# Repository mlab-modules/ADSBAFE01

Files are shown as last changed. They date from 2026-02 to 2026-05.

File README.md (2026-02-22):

# ADSBAFE01 - 1090 MHz ADS-B analog front-end

ADSBAFE01 is a complete 1090 MHz analog front-end for ADS-B / Mode-S reception. The module integrates RF filtering, low-noise amplification, logarithmic power detection and high-speed pulse shaping. It is intended to deliver a logic pulse stream corresponding to the RF envelope together with auxiliary RSSI information for sensitivity control and signal quality evaluation.

## Intended use

ADSBAFE01 is designed as an analog front-end for custom ADS-B receivers where digital demodulation and message decoding are implemented externally (MCU, FPGA, SDR backend, etc.). The module does not perform protocol decoding; it delivers time-accurate envelope pulses and auxiliary RSSI information for higher-layer processing.

## Functional overview

The RF signal enters through a 50 Ω MCX connector and immediately passes a 1090 MHz SAW band-pass filter (~30 MHz bandwidth). This suppresses strong out-of-band signals before amplification. The filtered signal is amplified by a BGA2818 LNA with approximately +30 dB gain. Then logarithmic power detector (AD8313) converts the RF envelope into a baseband voltage proportional to signal level. This node is intentionally kept lightly loaded because additional capacitance directly degrades slew rate and therefore timing accuracy of the detected pulses (see schematic notes ).

The detector output is processed in two parallel paths:

1. A high-speed comparator path generating digital pulses.
2. A peak-detection and sample-and-hold path providing RSSI information.

This separation allows reliable time-domain decoding while still exposing signal strength information for adaptive thresholding or diagnostics.

### Pulse extraction path

The comparator (MCP6566) converts the detector voltage into a CMOS pulse stream. Its propagation delay is on the order of 50 ns with ~20 ns fall time, which is sufficient for 1 µs ADS-B pulses.

The detection threshold is not fixed. It is derived from bias networks controlled by a 100 kΩ digital potentiometer (MCP4017, I²C). This allows software-controlled sensitivity adjustment without hardware modification. Low-frequency RC filtering in the bias network (fc ≈ 159 Hz) stabilizes the reference and suppresses slow variations.

The resulting `PULSES` output can be directly connected to:

* MCU timer capture input
* FPGA input
* Fast interrupt-capable GPIO

### RSSI and peak detection

For signal strength evaluation, the module implements an active peak detector (op-amp based). During a decode window, the peak value of the (inverted) log-detector output is sampled and held. The reset discharge time constant is approximately 44 ns, with ~95 % discharge in ~132 ns, enabling packet-level RSSI measurements without excessive memory between adjacent pulses.

The analog RSSI signal can be read by an external ADC if quantitative signal strength estimation is required.

### Electrical parameters

| Parameter | Value / Description |
| --- | --- |
| Supply voltage | 3.3 V |
| RF frequency | 1090 MHz (ADS-B / Mode-S) |
| RF input impedance | 50 Ω |
| LNA gain | ~+30 dB |
| Comparator delay | ~50 ns |
| Logic levels | 3.3 V CMOS |
| Threshold control  | I²C digital potentiometer |

The module includes input decoupling (10 µF + 100 nF) and supply protection (TVS diode) as shown in the schematic .

### Connectors

#### RF input (J3)

Type: MCX with impedance: 50 Ω

#### IO header (J1, 2×12)

The IO header exposes digital control, RSSI and interface signals. Series resistors provide basic IO protection and edge damping.

| Signal | Direction | Description |
| --- | --- | --- |
| PULSES | Output | Digital ADS-B envelope pulses |
| RF_LEVEL | Output (analog) | Log-detector RSSI voltage |
| DECODE | Input | Enables RSSI peak sampling |
| RSSI_HOLD | Input | Controls sample/hold state |
| RSSI_DSCHRG | Input | Forces RSSI capacitor discharge |
| MTL_HI_PWM  | Input | Comparator reference control (high) |
| MTL_LO_PWM  | Input | Comparator reference control (low)  |
| MTL_HI_BIAS | Internal / test | Bias node (high threshold) |
| MTL_LO_BIAS | Internal / test | Bias node (low threshold) |
| I2C1_SCL | Input | I²C clock (digital potentiometer) |
| I2C1_SDA | Bidirectional | I²C data |
| +3V3 | — | Supply |
| GND | — | Ground |

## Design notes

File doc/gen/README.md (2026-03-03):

# PCB

Board size: 50.29x50.29 mm (1.98x1.98 inches)

- This is the size of the rectangle that contains the board
- Thickness: 1.58 mm (62 mils)
- Material: FR4 (JLC 7628)
- Finish: ENIG
- Layers: 2
- Copper thickness: 35 µm

Solder mask: TOP / BOTTOM

- Color: Black

Silk screen: TOP / BOTTOM

- Color: White

Stackup:

Impedance controlled: YES

| Name | Type | Color | Thickness [µm]| Material | Er | Loss tan |
|---|---|---|---|---|---|---|
| F.SilkS | Top Silk Screen | White | | Liquid Photo | | |
| F.Paste | Top Solder Paste | | | | | |
| F.Mask | Top Solder Mask | Black | 15 | Epoxy (JLC) | 3.8 | 0.020 |
| F.Cu | copper | | 35 | | | |
| dielectric 1 | core | FR4 natural | 1484 | FR4 (JLC 7628)  | 4.4 | 0.020 |
| B.Cu | copper | | 35 | | | |
| B.Mask | Bottom Solder Mask | Black | 15 | Epoxy (JLC) | 3.8 | 0.020 |
| B.Paste | Bottom Solder Paste  | | | | | |
| B.SilkS | Bottom Silk Screen | White | | Liquid Photo | | |

# Important sizes

Clearance: 0.2 mm (8 mils)

Track width: 0.2 mm (8 mils)

- By design rules: 0.2 mm (8 mils)

Drill: 0.4 mm (16 mils)

- Vias: 0.4 mm (16 mils) [Design: 0.4 mm (16 mils)]
- Pads: 1.0 mm (39 mils)
- The above values are real drill sizes, they add 0.1 mm (4 mils) to plated holes (PTH)

Via: 0.7/0.3 mm (28/12 mils)

- By design rules: 0.3/0.3 mm (12/12 mils)
- Micro via: yes [0.2/0.1 mm (8/4 mils)]
- Buried/blind via: yes
- Total: 212 (thru: 212 buried/blind: 0 micro: 0)

Outer Annular Ring: 0.15 mm (6 mils)

- By design rules: 0.0 mm (0 mils)

Eurocircuits class: 4C
- Using min drill 0.4 mm for an OAR of 0.15 mm

# General stats

Components count: (SMD/THT)

- Top: 0/7 (THT)
- Bottom: 50/0 (SMD)

Defined tracks:

- 0.15 mm (6 mils)
- 0.25 mm (10 mils)
- 0.4 mm (16 mils)
- 0.6 mm (24 mils)
- 0.8 mm (31 mils)

Used tracks:

- 0.2 mm (8 mils) (8) defined: no
- 0.25 mm (10 mils) (153) defined: yes
- 0.3 mm (12 mils) (60) defined: no
- 0.5 mm (20 mils) (14) defined: no

Defined vias:

- 0.4/0.3 mm (16/12 mils)
- 0.8/0.4 mm (31/16 mils)

Used vias:

- 0.7/0.3 mm (28/12 mils) (Count: 212, Aspect: 2.3 A) defined: no

Holes (excluding vias):

- 0.89 mm (35 mils) (30)
- 1.5 mm (59 mils) (1)
- 1.7 mm (67 mils) (4)
- 3.0 mm (118 mils) (4)

Oval holes:

Drill tools (including vias and computing adjusts and rounding):

- 0.4 mm (16 mils) (212)
- 1.0 mm (39 mils) (30)
- 1.6 mm (63 mils) (1)
- 1.8 mm (71 mils) (4)
- 3.1 mm (122 mils) (4)

Solder paste stats:

Using a paste with 87.75 % alloy, that has an specific gravity for the alloy of 7.4 g/cm³
and 1.0 g/cm³ for the flux. This paste has an specific gravity of  4.15 g/cm³.

The stencil thickness is  0.12 mm.

| Side | Pads with paste | Area [mm²] | Paste [g] |
|---|---|---|---|
| Total  | 161 | 187.31 | 0.93 |

Note: this is just an approximation to the theoretical value. Margins of the solder mask and waste aren't computed.

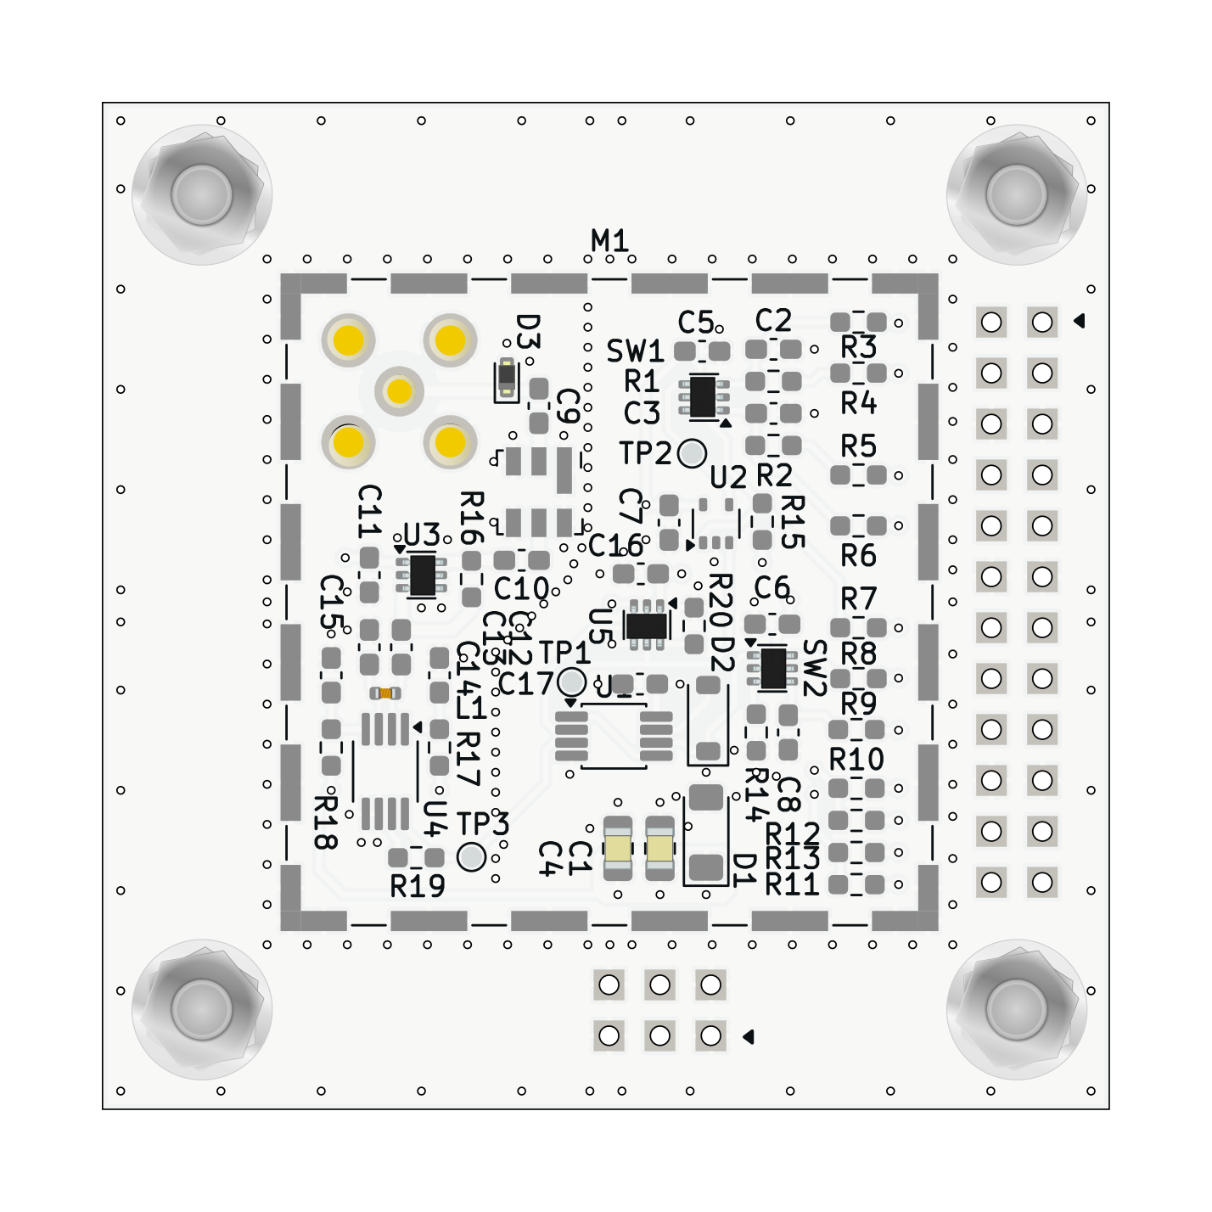
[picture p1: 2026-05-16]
doc/gen/img/ADSBAFE01-bottom.png

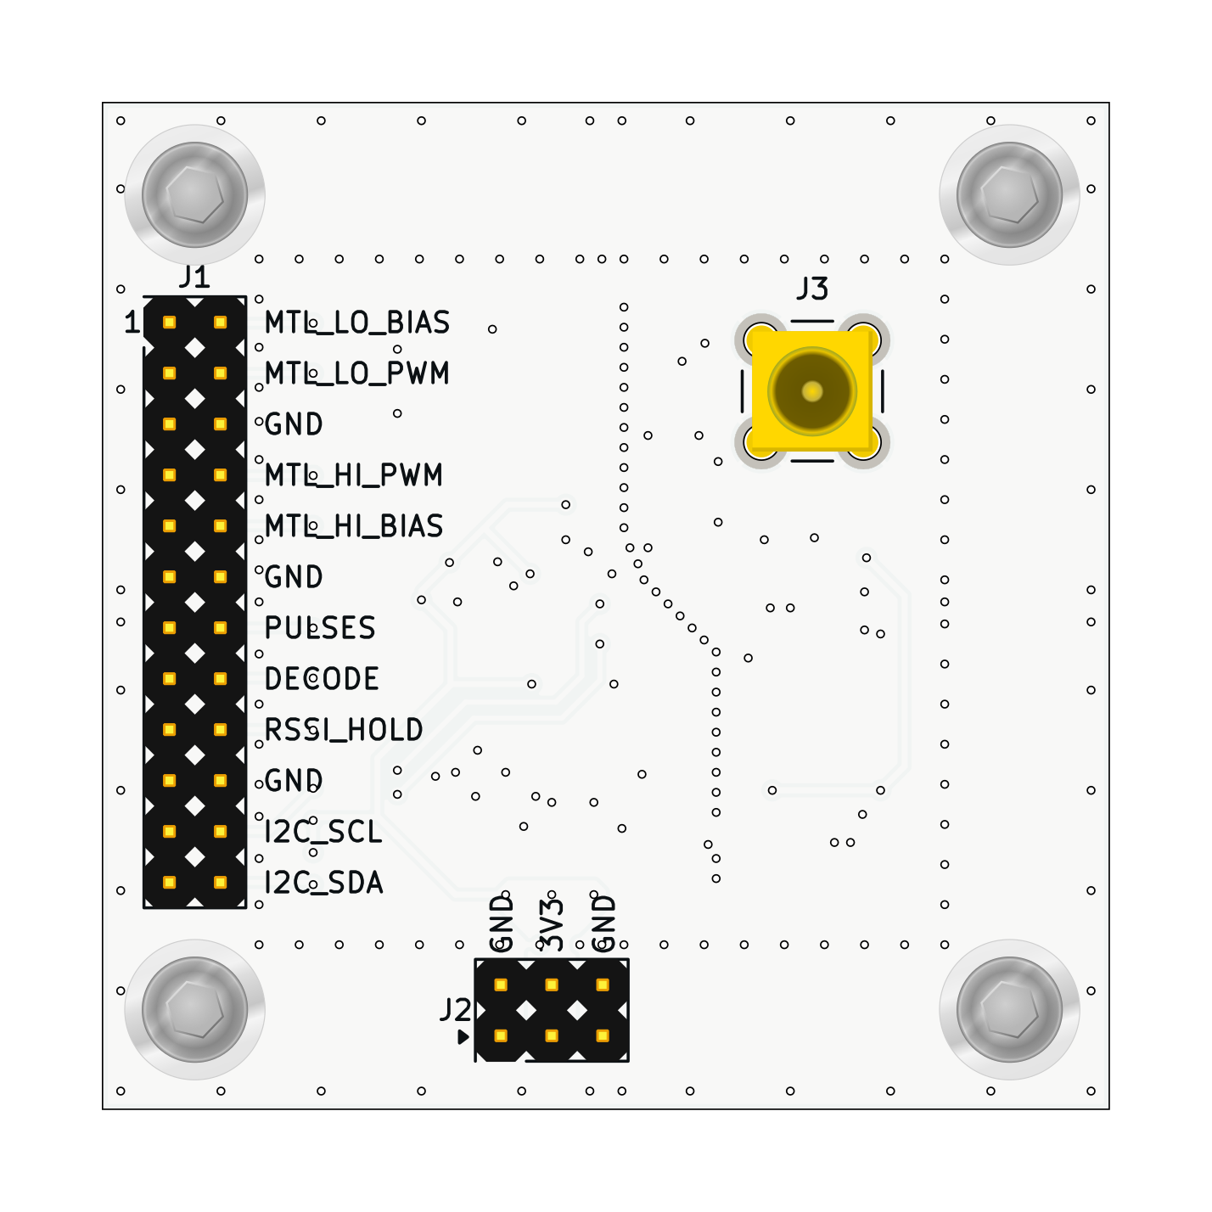
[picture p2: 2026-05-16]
doc/gen/img/ADSBAFE01-top.png

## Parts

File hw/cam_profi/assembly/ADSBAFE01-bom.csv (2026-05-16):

Component | Description | Part | References | Value | Footprint | Quantity Per PCB | Datasheet | mpn | ust_id
1 | Unpolarized capacitor | C | C12C13 | 3pF | C_0603_1608Metric_Pad1.08x0.95mm_HandSolder | 2 |  | CQ0402CRNPO9BN3R0
2 | Unpolarized capacitor | C | C9C10 | 39pF | C_0603_1608Metric_Pad1.08x0.95mm_HandSolder | 2 |  | CC0402JRNPO9BN390
3 | Unpolarized capacitor | C | C8C11 | 22nF | C_0603_1608Metric_Pad1.08x0.95mm_HandSolder | 2 |  | CC0402KRX7R9BB223
4 | Unpolarized capacitor | C | C2C3C5C6C7C14C15C16C17 | 0.1uF | C_0603_1608Metric_Pad1.08x0.95mm_HandSolder | 9 |  | CC0402KRX7R7BB104
5 | Unpolarized capacitor | C | C4 | 100nF | C_0805_2012Metric_Pad1.18x1.45mm_HandSolder | 1 |  |  | 5c70984712875079b91f8b4c
6 | Unpolarized capacitor | C | C1 | 10uF | C_0805_2012Metric_Pad1.18x1.45mm_HandSolder | 1 |  |  | 5c70984812875079b91f8bbe
7 | Schottky diode | D_Schottky | D2 | 20V 1A | D_SOD-123 | 1 |  | PMEG2010ER,115
8 | Bidirectional transient-voltage-suppression diode | D_TVS | D3 | 3.3VWM 0.6pF | D_SOD-523 | 1 | https://www.onsemi.com/pdf/datasheet/esd7351-d.pdf | ESD7351XV2T1G
9 | Zener diode | D_Zener | D1 | BZV55C-6,2V | D_MiniMELF | 1 |  |  | 604b0326128750769e5b0f93
10 | 2x03 2.54 mm pitch header, 2 pins next to each other are connected | HEADER_2x03_PARALLEL | J2 | HEADER_2x03_PARALLEL | Straight_2x03 | 1
11 | 2x12 2.54 mm pitch header, 2 pins next to each other are connected | HEADER_2x12_PARALLEL | J1 | HEADER_2x12_PARALLEL | Straight_2x12 | 1
12 | coaxial connector (BNC, SMA, SMB, SMC, Cinch/RCA, LEMO, ...) | Conn_Coaxial | J3 | MCX 6GHz 50R | MCX | 1 |  | U.FL-R-SMT-1(80)
13 | Inductor | L | L1 | 8.2nH RF | L_0402_1005Metric | 1 |  | 0402HP-8N2XJRW
14 | Two-piece EMI RF shielding cabinet | RFShield_TwoPieces | M1 | RFShield_TwoPieces | Laird_Technologies_BMI-S-204-F_32.00x32.00mm | 1 |  |  | 5c72751c1287500b4e11301a
15 | Resistor | R | R16R19 | 0R | R_0603_1608Metric_Pad0.98x0.95mm_HandSolder | 2 |  | RC0402JR-070RL
16 | Resistor | R | R17R18 | 10R | R_0603_1608Metric_Pad0.98x0.95mm_HandSolder | 2 |  | RC0402FR-0710RL
17 | Resistor | R | R3R4R5R6R7R8R9R10R11R14 | 20R | R_0603_1608Metric_Pad0.98x0.95mm_HandSolder | 10 |  | RC0402FR-0710KL RC0402FR-0720RL
18 | Resistor | R | R12R13R15R20 | 1k | R_0603_1608Metric_Pad0.98x0.95mm_HandSolder | 4 |  | RC0402FR-071KL
19 | Resistor | R | R1R2 | 10k | R_0603_1608Metric_Pad0.98x0.95mm_HandSolder | 2 |  | RC0402FR-0710KL
20 |  | SN74LVC1G3157 | SW1SW2 | SN74LVC1G3157 | SOT-363_SC-70-6 | 2 | https://www.ti.com/lit/ds/symlink/sn74lvc1g3157.pdf | SN74LVC1G3157DCKR
21 | 100 MHz to 2.5 GHz, 80 dB Logarithmic Detector / Controller, MSOP-8 | AD8313xRM | U4 | AD8313xRM | MSOP-8_3x3mm_P0.65mm | 1 | https://www.analog.com/media/en/technical-documentation/data-sheets/AD8313.pdf | AD8313ARMZ
22 | MMIC wideband amplifier, DC-2.2GHz, +30dB @ 2150MHz, 3.3V, SOT-363 | BGA2818 | U3 | BGA2818 | SOT-363_SC-70-6 | 1 | https://www.nxp.com/docs/en/data-sheet/BGA2818.pdf | BGA2818,115
23 | Low-Cost 128-Step Volatile I2C Digital Potentiometer, SC-70-6 | MCP4017-xxxxLT | U5 | MCP4017-104E 100k | SOT-363_SC-70-6 | 1 | http://ww1.microchip.com/downloads/en/DeviceDoc/22147a.pdf | MCP4017T-104E/LT
24 | Single 1.8V Low-Power Open-Drain Output Comparator, SOT-23-5/SC-70 | MCP6566 | U2 | MCP6566 | SOT-353_SC-70-5 | 1 | http://ww1.microchip.com/downloads/en/DeviceDoc/MCP6566-6R-6U-7-9-1.8V-Low-Power-Open-Drain-Output-Comparator-DS20002143G.pdf | MCP6566T-E/LT
25 | 200-MHz, Rail-to-Rail I/O, VSSOP-8 | TLV3542 | U1 | TLV3542 | VSSOP-8_3x3mm_P0.65mm | 1 | https://www.ti.com/lit/ds/symlink/tlv3542.pdf | TLV3542IDGKR
26 |  | SAW-6_Filter | X1 | SF2321D | Filter_SAW-6_3.8x3.8mm | 1 | https://www.mouser.com/datasheet/2/1100/sf2321d-1917641.pdf | SF2321D

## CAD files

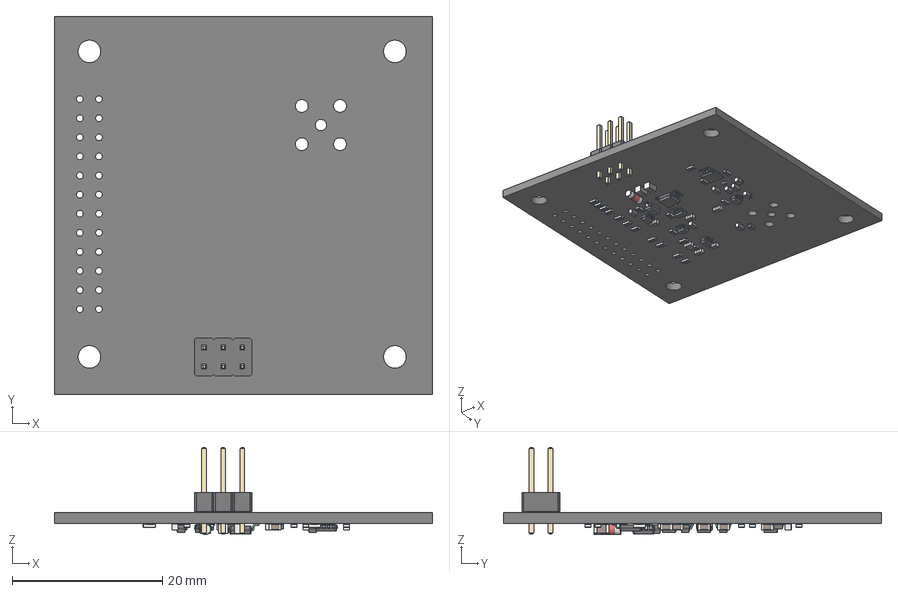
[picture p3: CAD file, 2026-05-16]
doc/gen/ADSBAFE01.step
50.3 x 50.3 x 11.6 mm
PinHeader_2x03_P2.54mm_Vertical
D_SOD-523
R_0603_1608Metric x 20
C_0603_1608Metric x 15
C_0805_2012Metric x 2
MSOP-8_3x3mm_P0.65mm
SOT-363_SC-70-6 x 4
VSSOP-8_3x3mm_P0.65mm
D_MiniMELF
D_SOD-123
L_0402_1005Metric
SOT-353_SC-70-5
kibot_9g2yru_4_PCB

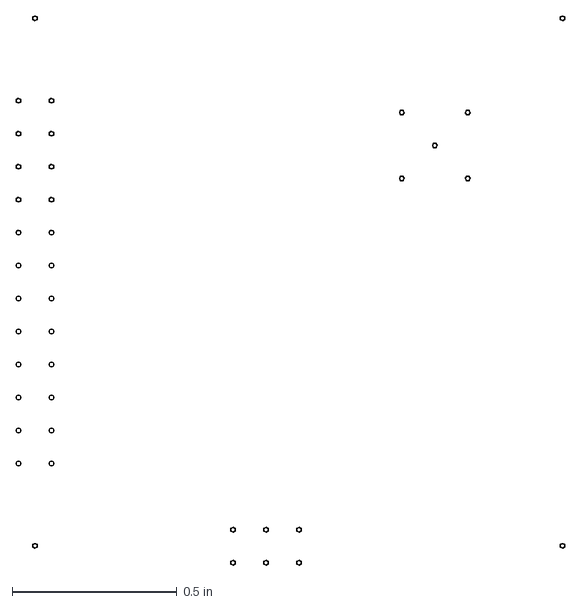
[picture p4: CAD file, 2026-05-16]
doc/gen/dxf/ADSBAFE01-User_2.dxf
1.66 x 1.66 in

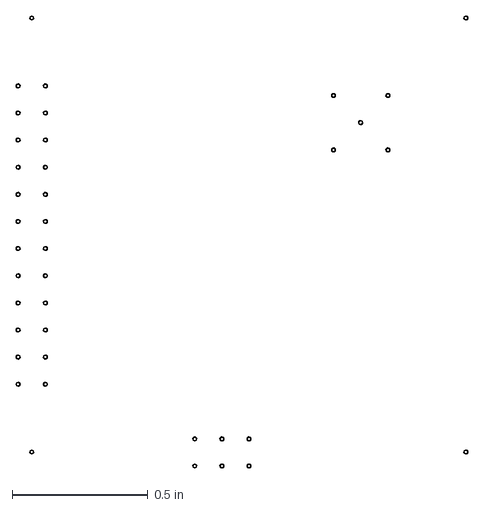
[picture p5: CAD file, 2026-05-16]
doc/gen/dxf/ADSBAFE01-F_Adhesive.dxf
1.66 x 1.66 in

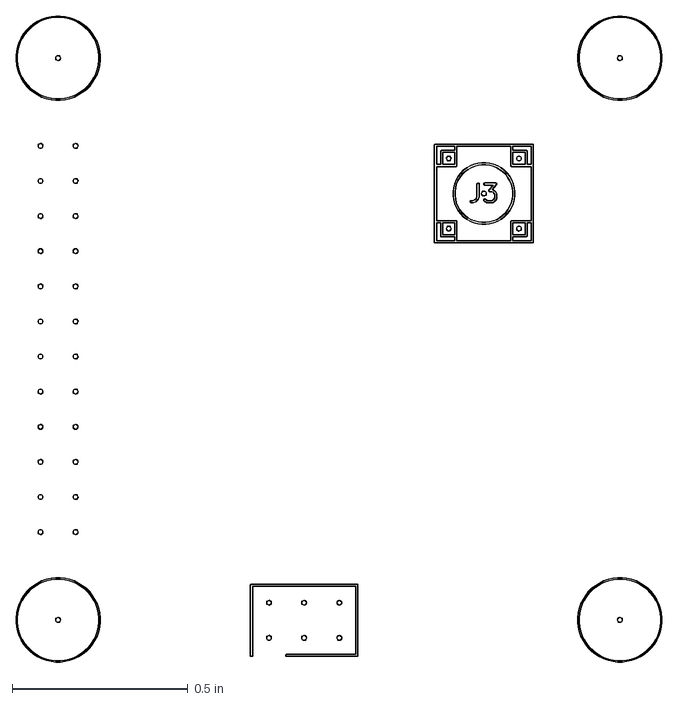
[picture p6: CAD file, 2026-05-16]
doc/gen/dxf/ADSBAFE01-F_Fab.dxf
1.84 x 1.84 in

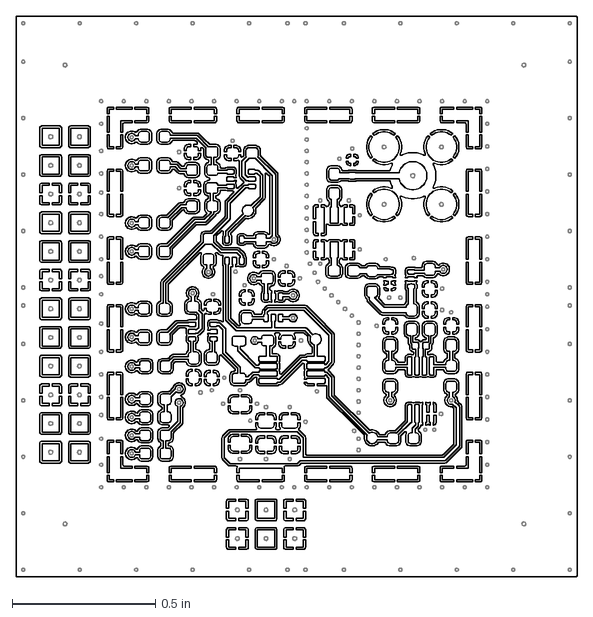
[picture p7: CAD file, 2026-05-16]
doc/gen/dxf/ADSBAFE01-B_Cu.dxf
1.96 x 1.96 in

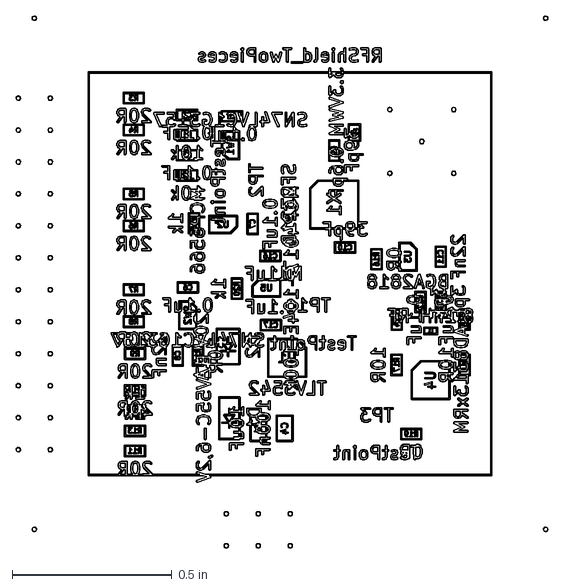
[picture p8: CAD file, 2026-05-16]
doc/gen/dxf/ADSBAFE01-B_Fab.dxf
1.66 x 1.66 in

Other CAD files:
doc/gen/dxf/ADSBAFE01-B_Courtyard.dxf
doc/gen/dxf/ADSBAFE01-B_Mask.dxf
doc/gen/dxf/ADSBAFE01-B_Paste.dxf
doc/gen/dxf/ADSBAFE01-B_Silkscreen.dxf
doc/gen/dxf/ADSBAFE01-Edge_Cuts.dxf
doc/gen/dxf/ADSBAFE01-F_Cu.dxf
doc/gen/dxf/ADSBAFE01-F_Mask.dxf
doc/gen/dxf/ADSBAFE01-F_Silkscreen.dxf

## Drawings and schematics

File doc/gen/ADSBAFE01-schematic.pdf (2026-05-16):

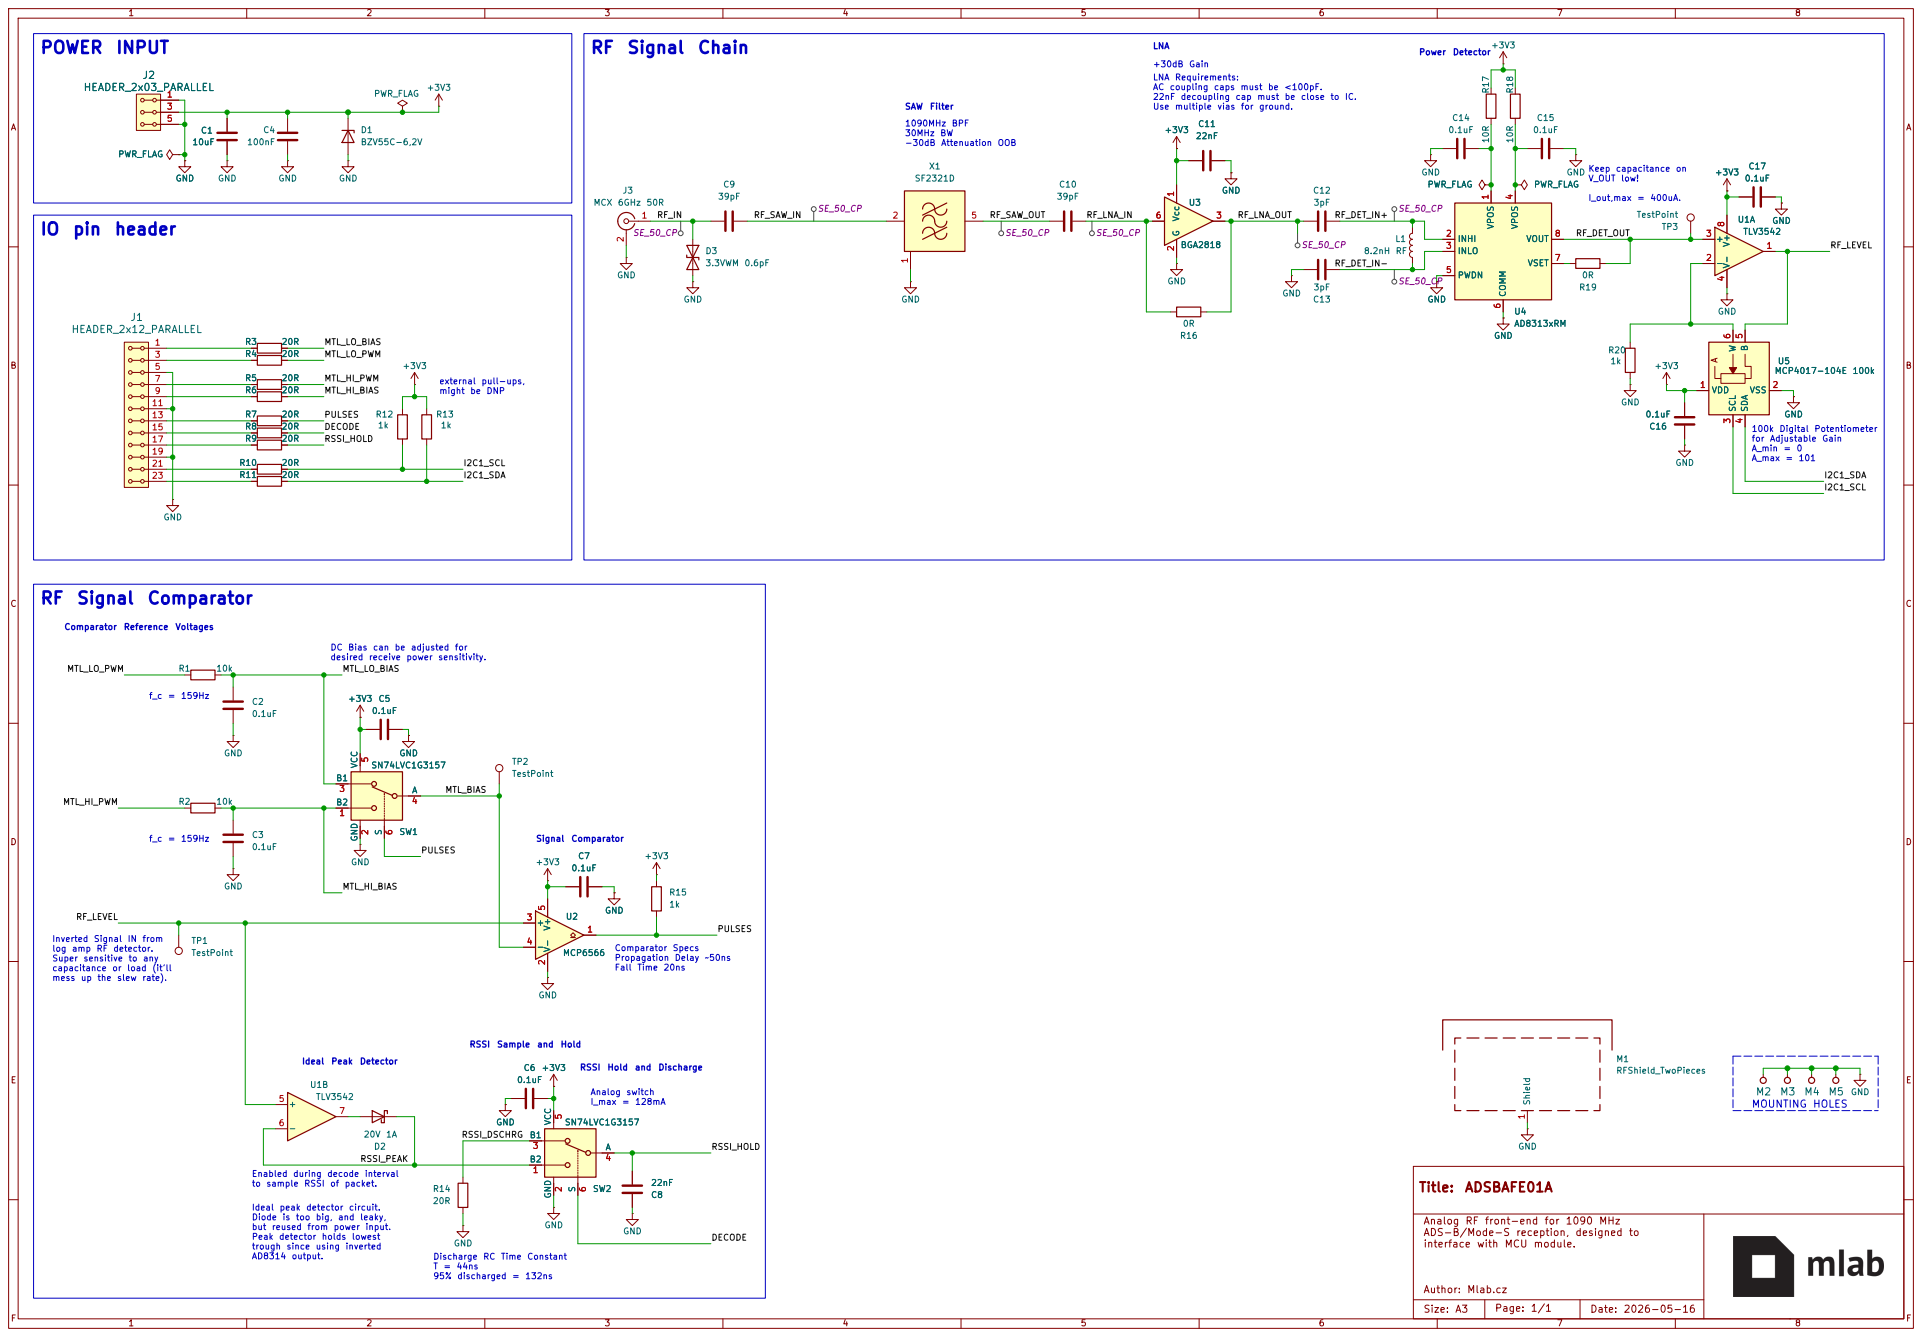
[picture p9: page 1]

A_max = 101 +30dB Gain 1090MHz BPF 30MHz BW -30dB Attenuation OOB

I_out,max = 400uA. LNA Requirements: AC coupling caps must be <100pF. 22nF decoupling cap must be close to IC. Use multiple vias for ground.

VSS

Propagation Delay ~50ns Fall Time 20ns DC Bias can be adjusted for desired receive power sensitivity.
MTL_HI_BIAS MTL_LO_BIAS

Inverted Signal IN from
log amp RF detector. Super sensitive to any capacitance or load (it'll mess up the slew rate).

DECODE RSSI Sample and Hold

RSSI Hold and Discharge

Enabled during decode interval to sample RSSI of packet.

Ideal peak detector circuit. Diode is too big, and leaky, but reused from power input. Peak detector holds lowest

Analog RF front-end for 1090 MHz ADS-B/Mode-S reception, designed to interface with MCU module.

trough since using inverted
AD8314 output.

Size: A3 | Page: 1/1 | Date: 2026-05-16

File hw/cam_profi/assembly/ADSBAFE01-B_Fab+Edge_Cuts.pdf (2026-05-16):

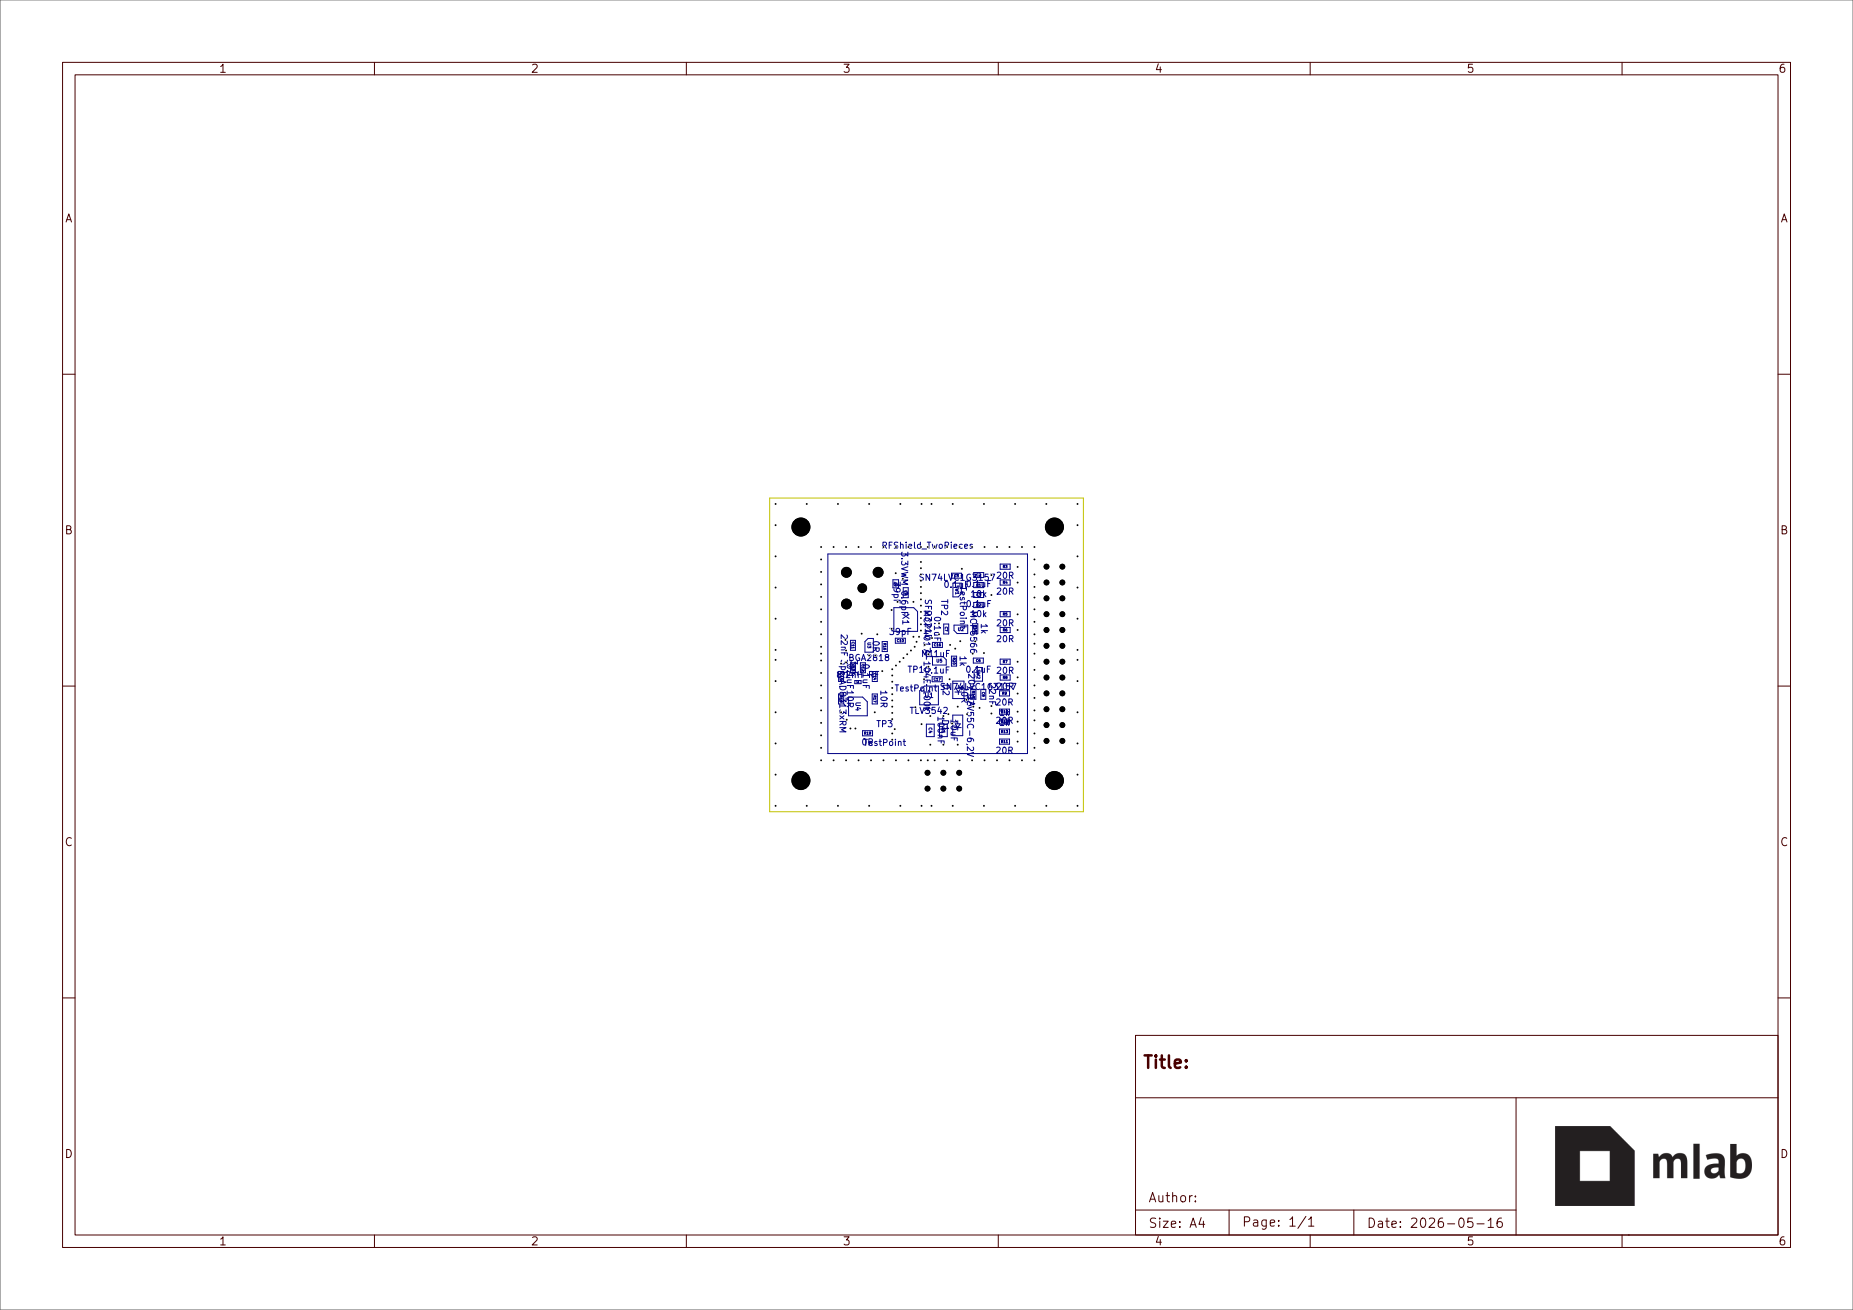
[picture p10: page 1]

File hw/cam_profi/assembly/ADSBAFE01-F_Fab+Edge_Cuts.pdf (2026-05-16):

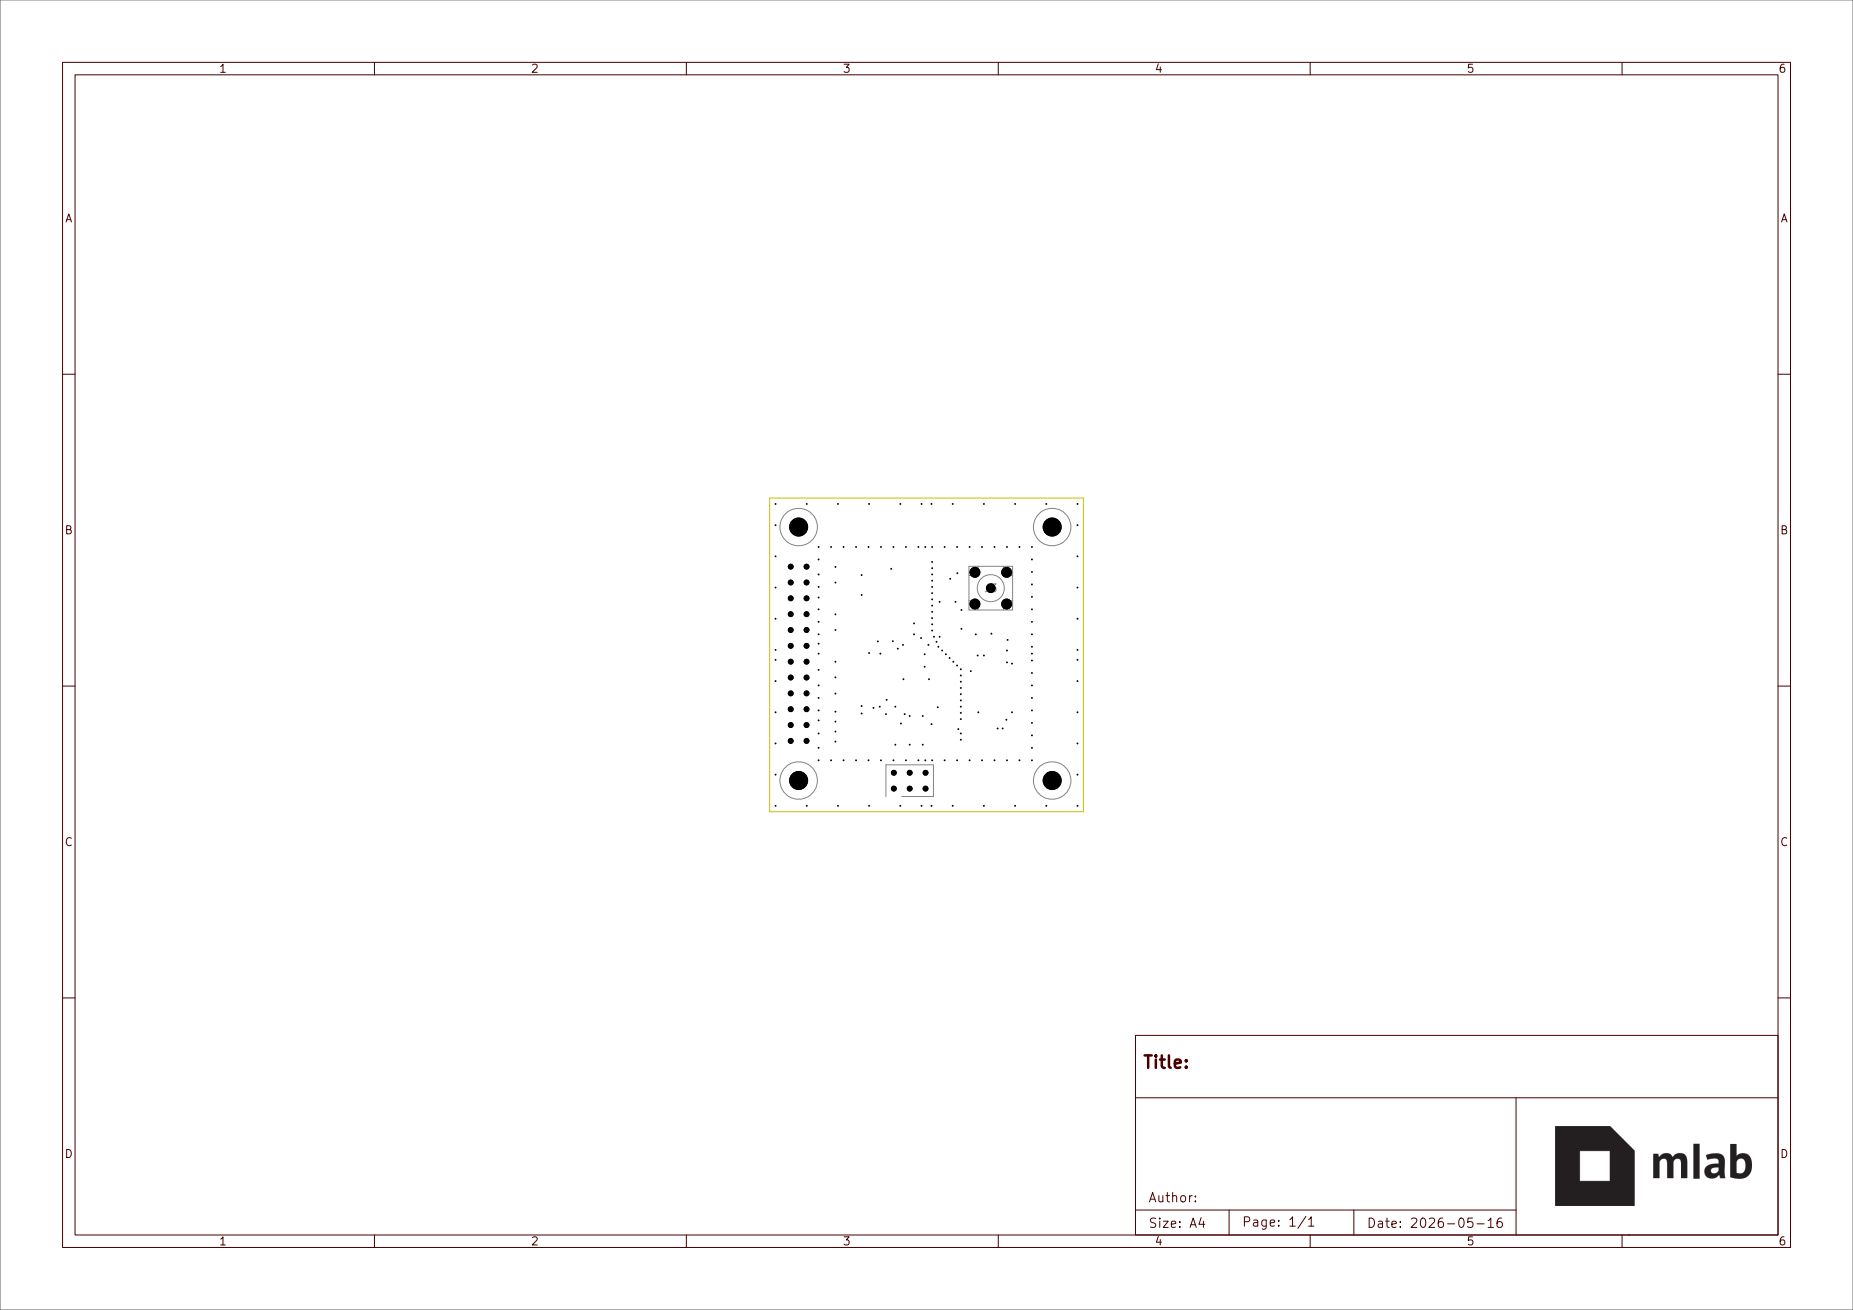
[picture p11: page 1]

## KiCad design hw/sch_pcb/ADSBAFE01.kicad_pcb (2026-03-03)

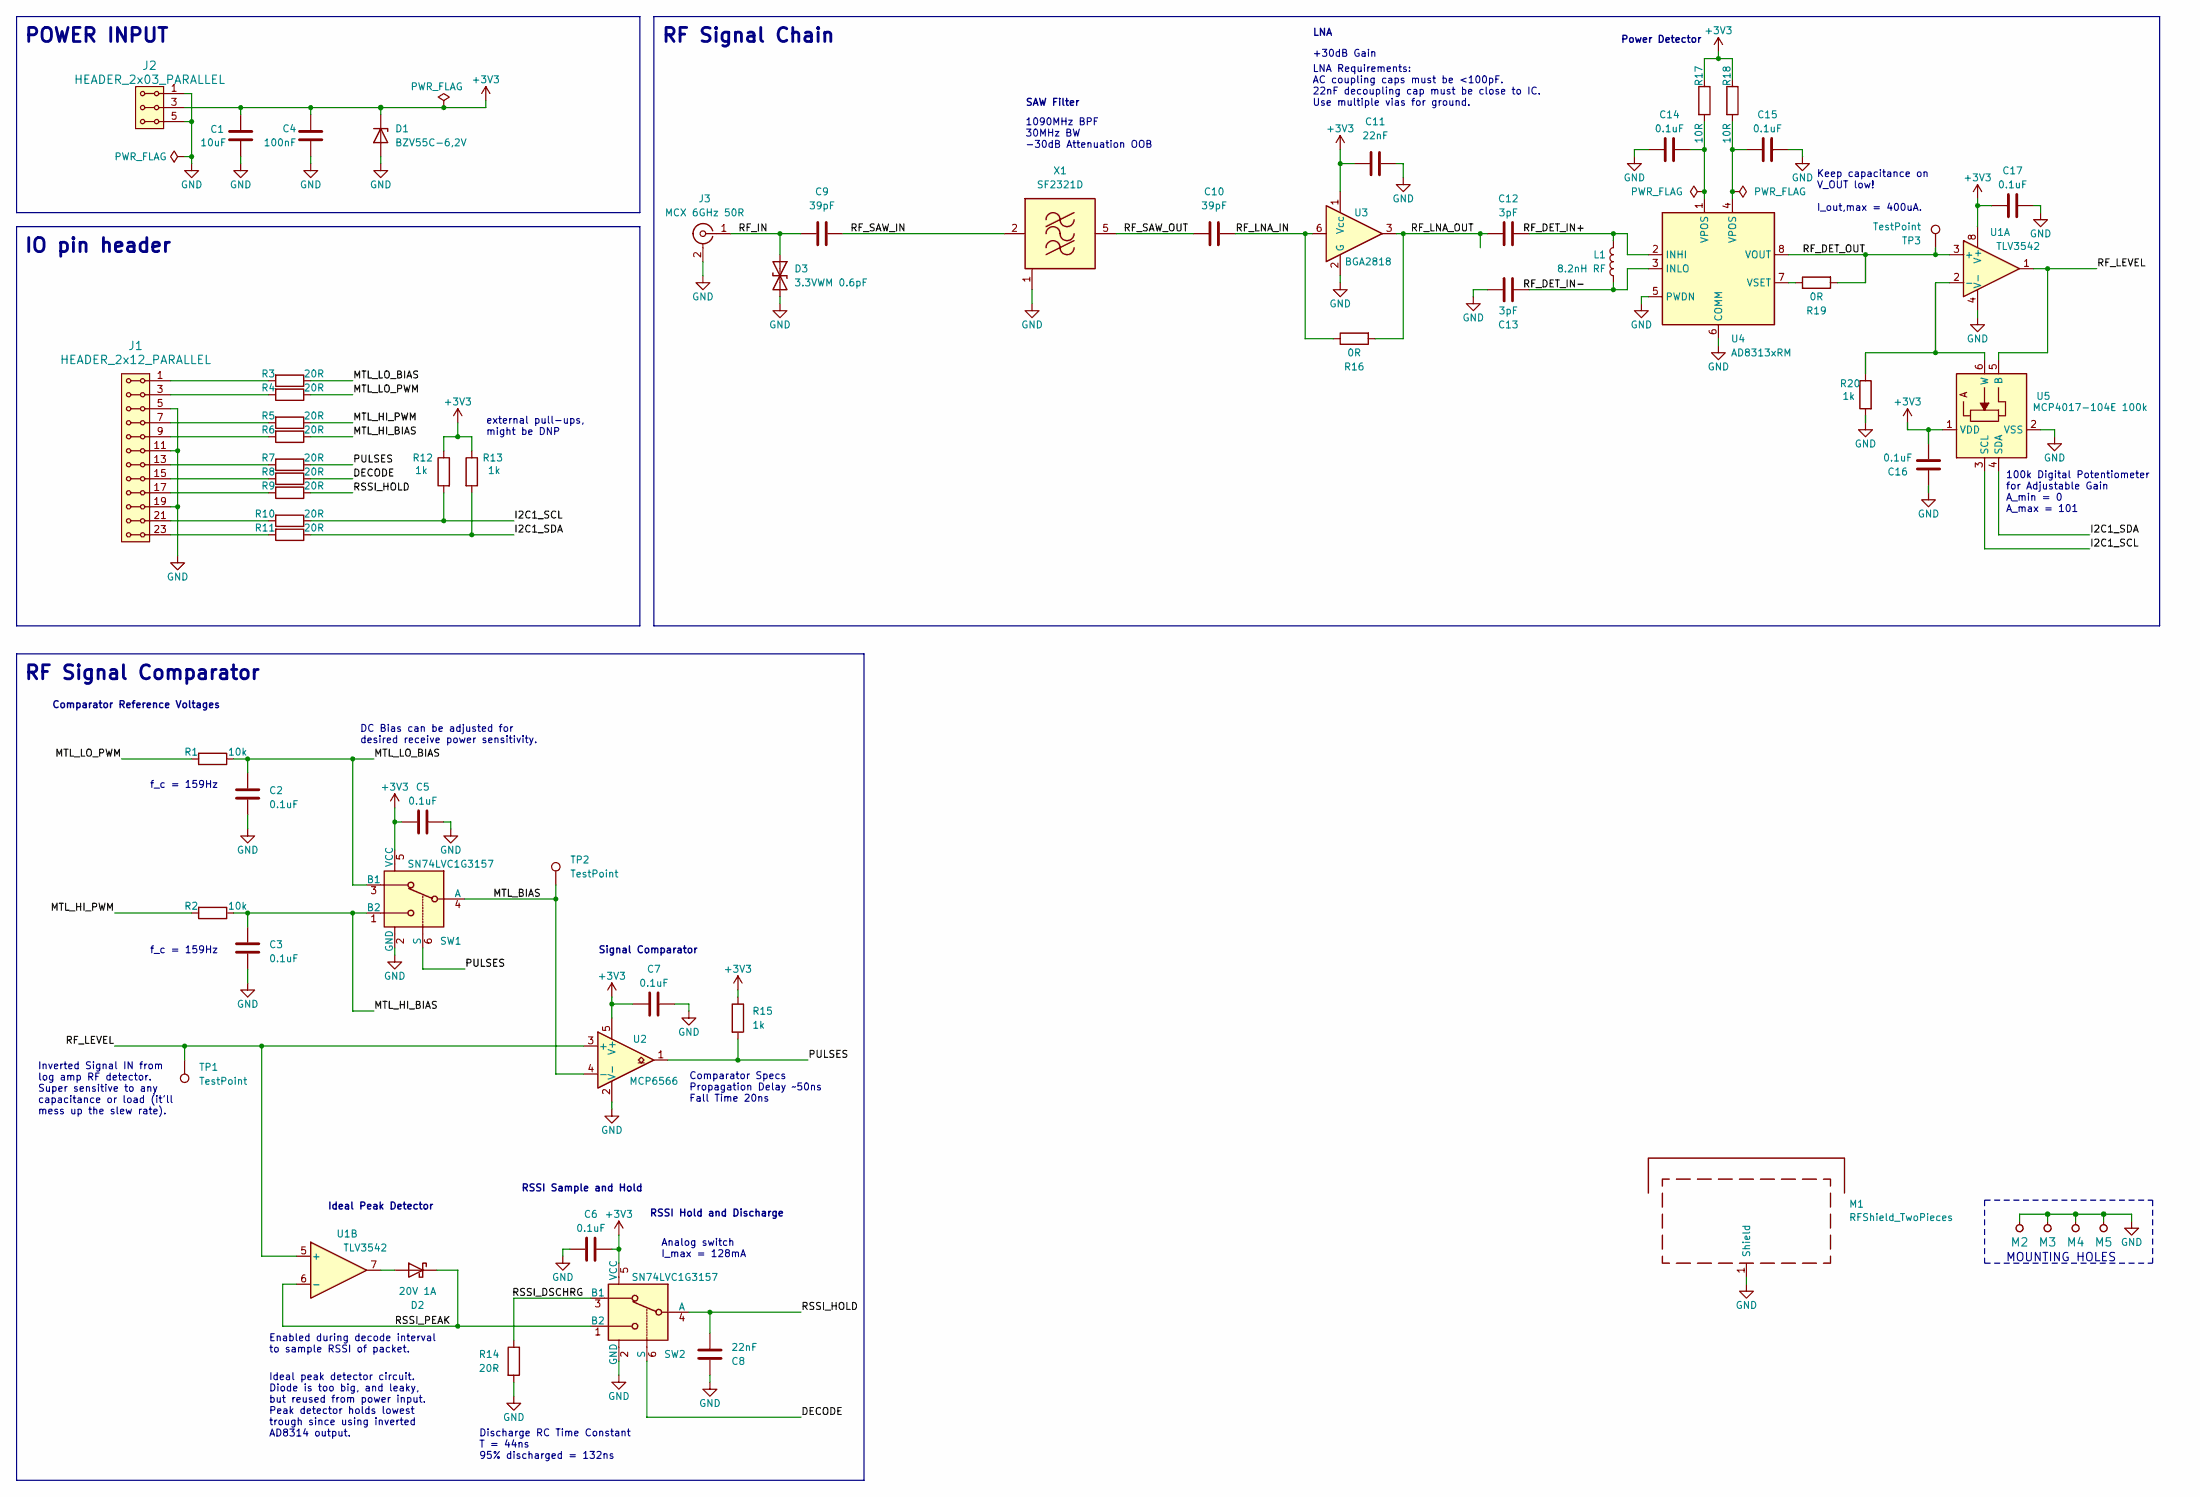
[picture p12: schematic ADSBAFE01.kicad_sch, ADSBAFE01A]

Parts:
C1: 10uF; C_0805_2012Metric_Pad1.18x1.45mm_HandSolder
C2, C3, C5, C6, C7, C14, C15, C16, C17: 0.1uF; C_0603_1608Metric_Pad1.08x0.95mm_HandSolder; MPN CC0402KRX7R7BB104
C4: 100nF; C_0805_2012Metric_Pad1.18x1.45mm_HandSolder
C8, C11: 22nF; C_0603_1608Metric_Pad1.08x0.95mm_HandSolder; MPN CC0402KRX7R9BB223
C9, C10: 39pF; C_0603_1608Metric_Pad1.08x0.95mm_HandSolder; MPN CC0402JRNPO9BN390
C12, C13: 3pF; C_0603_1608Metric_Pad1.08x0.95mm_HandSolder; MPN CQ0402CRNPO9BN3R0
D1: BZV55C-6,2V; D_MiniMELF
D2: 20V 1A; D_SOD-123; MPN PMEG2010ER,115
D3: 3.3VWM 0.6pF; D_SOD-523; MPN ESD7351XV2T1G
J1: HEADER_2x12_PARALLEL; Straight_2x12
J2: HEADER_2x03_PARALLEL; Straight_2x03
J3: MCX 6GHz 50R; MCX; MPN U.FL-R-SMT-1(80)
L1: 8.2nH RF; L_0402_1005Metric; MPN 0402HP-8N2XJRW
M1: RFShield_TwoPieces; Laird_Technologies_BMI-S-204-F_32.00x32.00mm
M2, M3, M4, M5: HOLE; MountingHole_3mm
R1, R2: 10k; R_0603_1608Metric_Pad0.98x0.95mm_HandSolder; MPN RC0402FR-0710KL
R3, R4, R5, R6, R7, R8, R9, R10, R11: 20R; R_0603_1608Metric_Pad0.98x0.95mm_HandSolder; MPN RC0402FR-0710KL
R12, R13, R15, R20: 1k; R_0603_1608Metric_Pad0.98x0.95mm_HandSolder; MPN RC0402FR-071KL
R14: 20R; R_0603_1608Metric_Pad0.98x0.95mm_HandSolder; MPN RC0402FR-0720RL
R16, R19: 0R; R_0603_1608Metric_Pad0.98x0.95mm_HandSolder; MPN RC0402JR-070RL
R17, R18: 10R; R_0603_1608Metric_Pad0.98x0.95mm_HandSolder; MPN RC0402FR-0710RL
SW1, SW2: SN74LVC1G3157; SOT-363_SC-70-6; MPN SN74LVC1G3157DCKR
TP1, TP2, TP3: TestPoint; TestPoint_Pad_D1.0mm
U1: TLV3542; VSSOP-8_3x3mm_P0.65mm; MPN TLV3542IDGKR
U2: MCP6566; SOT-353_SC-70-5; MPN MCP6566T-E/LT
U3: BGA2818; SOT-363_SC-70-6; MPN BGA2818,115
U4: AD8313xRM; MSOP-8_3x3mm_P0.65mm; MPN AD8313ARMZ
U5: MCP4017-104E 100k; SOT-363_SC-70-6; MPN MCP4017T-104E/LT
X1: SF2321D; Filter_SAW-6_3.8x3.8mm; MPN SF2321D

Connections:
+3V3: C1.1, C4.1, C5.1, C6.2, C7.1, C11.1, C16.2, C17.1, D1.1 (K), J2.3, J2.4, R12.1, R13.1, R15.1, R17.1, R18.1, SW1.5 (VCC), SW2.5 (VCC), U1.8 (V+), U2.5 (V+), U3.1 (Vcc), U5.1 (VDD)
/DECODE: R8.1, SW2.6 (S)
/I2C1_SCL: R10.1, R12.2, U5.3 (SCL)
/I2C1_SDA: R11.1, R13.2, U5.4 (SDA)
/MTL_BIAS: SW1.4 (A), TP2.1, U2.4 (-)
/MTL_HI_BIAS: C3.1, R2.1, R6.1, SW1.1 (B2)
/MTL_HI_PWM: R2.2, R5.1
/MTL_LO_BIAS: C2.1, R1.1, R3.1, SW1.3 (B1)
/MTL_LO_PWM: R1.2, R4.1
/PULSES: R7.1, R15.2, SW1.6 (S), U2.1
/RF_DET_IN+: C12.2, L1.1, U4.2 (INHI)
/RF_DET_IN-: C13.2, L1.2, U4.3 (INLO)
/RF_DET_OUT: R19.2, TP3.1, U1.3 (+), U4.8 (VOUT)
/RF_IN: C9.1, D3.1 (A1), J3.1 (In)
/RF_LEVEL: TP1.1, U1.1, U1.5 (+), U2.3 (+), U5.5 (B)
/RF_LNA_IN: C10.2, R16.1, U3.6
/RF_LNA_OUT: C12.1, R16.2, U3.3
/RF_SAW_IN: C9.2, X1.2 (IN)
/RF_SAW_OUT: C10.1, X1.5 (OUT)
/RSSI_DSCHRG: R14.1, SW2.3 (B1)
/RSSI_HOLD: C8.2, R9.1, SW2.4 (A)
/RSSI_PEAK: D2.1 (K), SW2.1 (B2), U1.6 (-)
GND: C1.2, C2.2, C3.2, C4.2, C5.2, C6.1, C7.2, C8.1, C11.2, C13.1, C14.1, C15.2, C16.1, C17.2, D1.2 (A), D3.2 (A2), J1.5, J1.6, J1.11, J1.12, J1.19, J1.20, J2.1, J2.2, J2.5, J2.6, J3.2 (Ext), M1.1 (Shield), M2.1, M3.1, M4.1, M5.1, R14.2, R20.2, SW1.2 (GND), SW2.2 (GND), U1.4 (V-), U2.2 (V-), U3.2 (G), U3.4 (G), U3.5 (G), U4.5 (PWDN), U4.6 (COMM), U5.2 (VSS), X1.1 (GND), X1.3 (GND), X1.4 (GND), X1.6 (GND)
unnamed: C14.2, R17.2, U4.1 (VPOS)
unnamed: C15.1, R18.2, U4.4 (VPOS)
unnamed: D2.2 (A), U1.7
unnamed: J1.1, J1.2, R3.2
unnamed: J1.3, J1.4, R4.2
unnamed: J1.7, J1.8, R5.2
unnamed: J1.9, J1.10, R6.2
unnamed: J1.13, J1.14, R7.2
unnamed: J1.15, J1.16, R8.2
unnamed: J1.17, J1.18, R9.2
unnamed: J1.21, J1.22, R10.2
unnamed: J1.23, J1.24, R11.2
unnamed: R20.1, U1.2 (-), U5.6 (W)
unnamed: R19.1, U4.7 (VSET)

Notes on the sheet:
LNA
Comparator Reference Voltages
1090MHz BPF 30MHz BW -30dB Attenuation OOB
Keep capacitance on V_OUT low! I_out,max = 400uA.
100k Digital Potentiometer for Adjustable Gain A_min = 0 A_max = 101
Ideal Peak Detector
f_c = 159Hz
Analog switch I_max = 128mA
Enabled during decode interval to sample RSSI of packet.
RF Signal Comparator
SAW Filter
MOUNTING HOLES
RF Signal Chain
+30dB Gain
Signal Comparator
f_c = 159Hz
Comparator Specs Propagation Delay ~50ns Fall Time 20ns
RSSI Sample and Hold
DC Bias can be adjusted for desired receive power sensitivity.
LNA Requirements: AC coupling caps must be <100pF. 22nF decoupling cap must be close to IC. Use multiple vias for ground.
RSSI Hold and Discharge
IO pin header
external pull-ups, might be DNP
Ideal peak detector circuit. Diode is too big, and leaky, but reused from power input. Peak detector holds lowest trough since using inverted AD8314 output.
POWER INPUT
Power Detector
Discharge RC Time Constant T = 44ns 95% discharged = 132ns
Inverted Signal IN from log amp RF detector. Super sensitive to any capacitance or load (it'll mess up the slew rate).

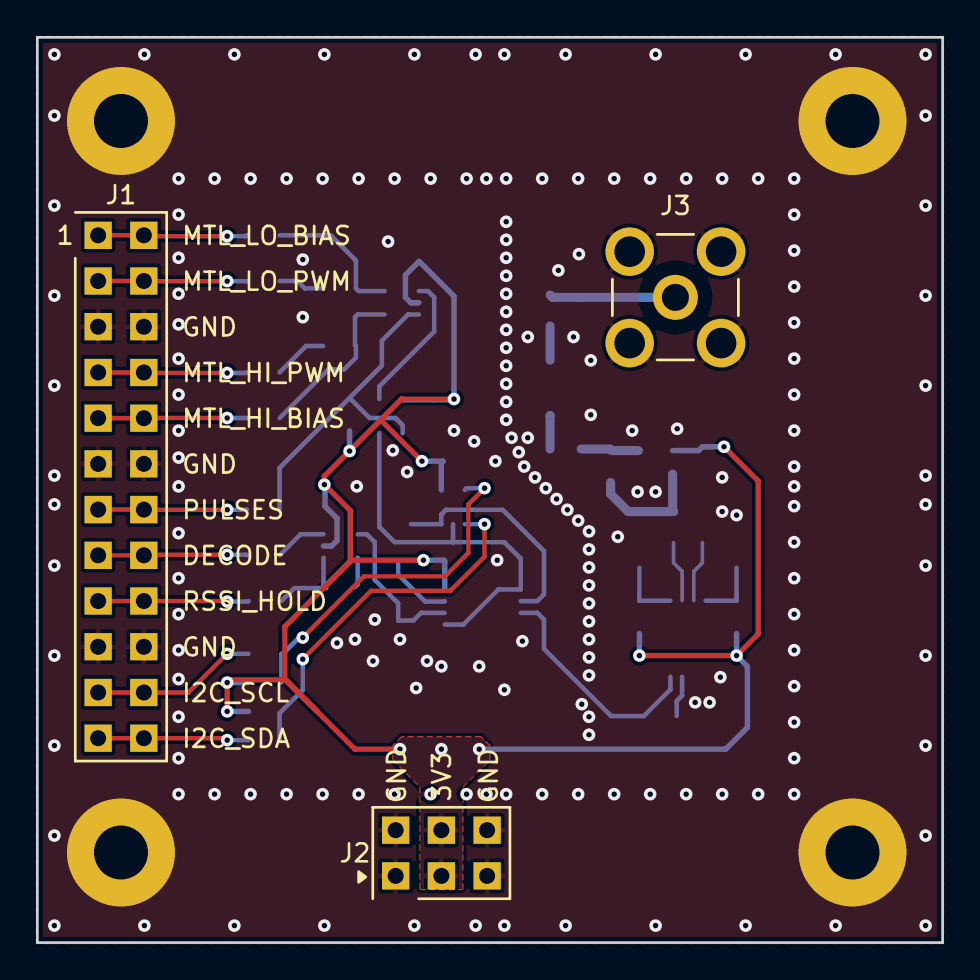
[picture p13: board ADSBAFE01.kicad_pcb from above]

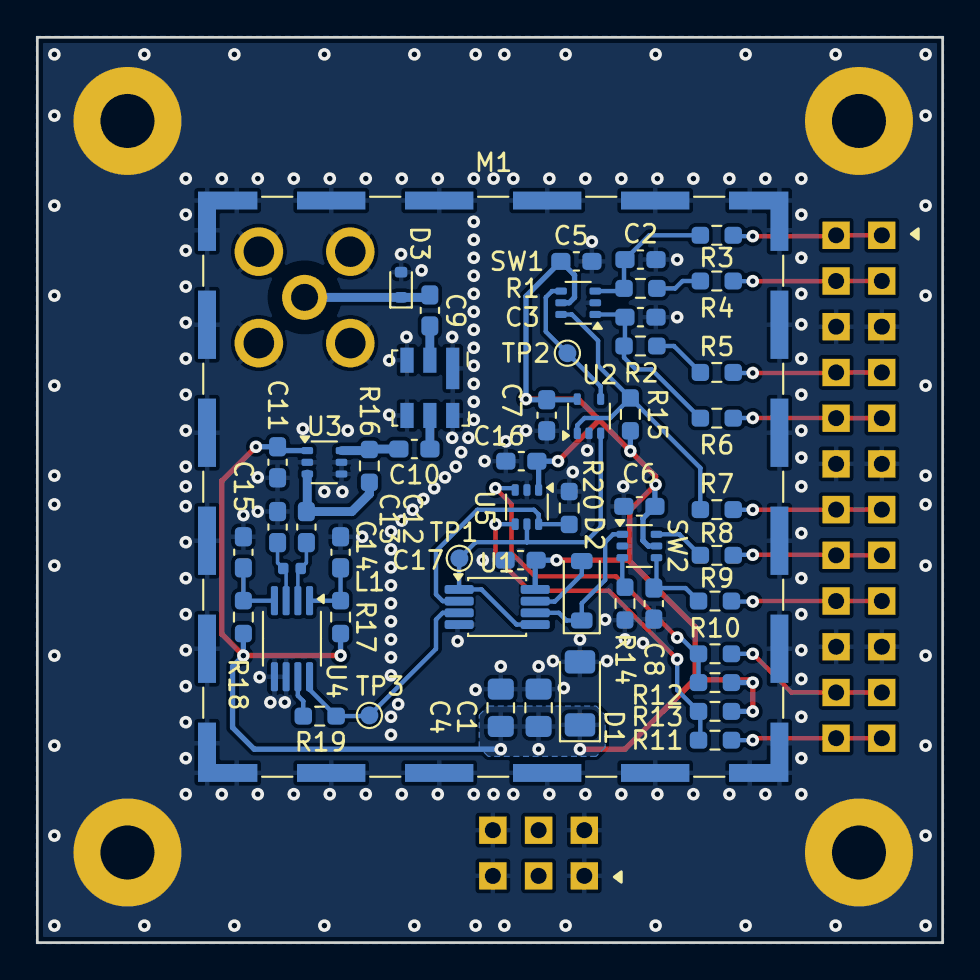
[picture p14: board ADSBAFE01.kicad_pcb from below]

Board: 2 copper layers, 50.3 x 50.3 mm, 60 parts (53 on the bottom side), 37 nets.

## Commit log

2026-02-18 first draft of layout
    Parts placement viable. Traces sketched only to test whether connections
    are viable.
    [ADSBAFE01.kicad_pcb, ADSBAFE01.kicad_sch]
2026-02-20 Layout done, silk WIP
    [ADSBAFE01.kicad_pcb, ADSBAFE01.kicad_sch]
2026-02-20 changed footprint U3, silk started
    Footprint of U3 changed to edited version which suits clearence 0,2mm.
    [ADSBAFE01.kicad_pcb, ADSBAFE01.kicad_sch]
2026-02-21 silk done
    [ADSBAFE01.kicad_pcb]
2026-02-21 reannotated, added 3d model of SAW
    [ADSBAFE01.kicad_pcb, ADSBAFE01.kicad_sch, SF2321D--3DModel-STEP-672324.STEP]
2026-02-21 symbols properties cleanup, final checks OK
    [ADSBAFE01.kicad_pcb, ADSBAFE01.kicad_sch]
2026-02-22 added via stitching
    [ADSBAFE01.kicad_pcb]
2026-02-22 Update workflows to KiCADv9.
2026-02-22 Automatic update of KiCAD outputs
    [ADSBAFE01-B_Adhesive.dxf, ADSBAFE01-B_Courtyard.dxf, ADSBAFE01-B_Cu.dxf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]
2026-02-22 Layout improvements.
    [ADSBAFE01.kicad_pcb, ADSBAFE01.kicad_sch]
2026-03-03 Move footprints to standard MLAB libraries.
    [ADSBAFE01.kicad_pcb, ADSBAFE01.kicad_sch, SF2321D--3DModel-STEP-672324.STEP]
